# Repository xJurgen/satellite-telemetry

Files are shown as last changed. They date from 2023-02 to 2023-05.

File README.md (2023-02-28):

# satellite-telemetry

This is a college project with an objective to create a CubeSat-like device from scratch.

The code is intended for a Blackpill (STM32F411CE) board and its functionality provides an access to the satellite sensors.
In the final design the Blackpill is connected to an RPi Zero W (V1.1) via USART1 and responds on the RPi requests.

Implemented features:
	
	- Command processing
	- Communication on USART1

Work in progress:
	
	- Light and temperature sensing using ADC

Planned features:

	- Battery management (solar panels input, battery output, shut-off when critically low level of battery..)
	- Gyroscope reading (?)

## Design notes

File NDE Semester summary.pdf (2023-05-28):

Space Applications Study Course 25.4.2023

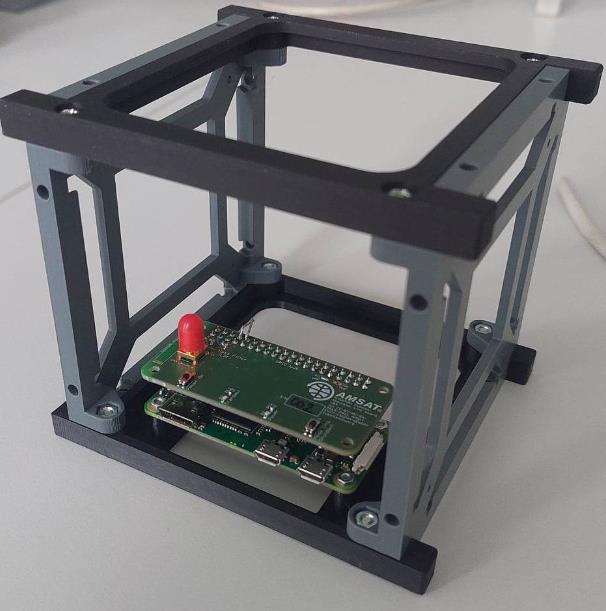
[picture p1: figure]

D. Sedláček (221347), A. Bekeč (221096), M. Borovička (208436), M. Picka (201573), M. Roman (222951), J. Veverka (205866)

### MPA-NDE Semestral Report: Development of a Power PCB Control Board for CubeSatSim Educational Platform

Project Overview

At the beginning of the semester, a series of basic tests was conducted to familiarize students with the CubeSatSim software and the Raspberry Pi Zero platform. These tests included Automated Frequency Shift Keying (AFSK) Mode Tests, Slow Scan Television (SSTV) Tests, Frequency Shift Keying (FSK), and Binary Phase Shift Keying (BPSK) FoxTelem Tests. These experiments laid the foundation for understanding the communication and telemetry protocols commonly used in nanosatellite technology.

Based on the provided platform, the class identified an opportunity to improve the CubeSatSim design by proposing a new power control board PCB. The aim was to enhance the power management capabilities of the simulated CubeSat, mainly to offer alternative options to provide power to the whole system. Throughout the remainder of the semester, the focus was centered around the design and development of this new power control board. The project was divided into several phases: initial testing, research, feasibility study, prototyping, schematic design, software development, PCB design, and fabrication & testing. By the end of the semester, the class successfully completed the design of the PCB and partially demonstrated its functionality.

Phase Zero: Initial Testing

In its initial state, the CubeSat consisted of a Raspberry pi zero and a CubeSatSim Lite board. These components were placed in the basic frame structure. As can be seen on Figure 1.

Figure 1 Initial state

The communication tests were performed first with the SDRsharp program. An RTL-SDR R860T2 USB receiver was connected to the computer, with the help of which this communication was successfully completed. Testing of sending basic telemetry data was done using the FoxTelem program. A Finally, a test of sending a picture using the MMSSTV program was also carried out. This program works in cooperation with SDRsharp, with which it was connected using a virtual audio cable and decoded the image from the audio signal. All tests were successful and created a basis for further improvement possibilities

Phase One: Research

As CubeSats are very small, as they aim to be very cost-effective, one of the key challenges in their design is ensuring reliable and efficient ways to generate power and coming up with methods for power management.

Solar Panels are the most common power source for CubeSats. There are several types of solar panels, including monocrystalline, polycrystalline, and thin-film panels. Typically, CubeSats use monocrystalline (often multi-junction) layers as they offer the highest efficiency. An exemplary structure is a triple-junction GaAs cell. These solar cells are lightweight, have a high power-to-weight ratio, and can provide power for the duration of the CubeSat mission. Depending on the CubeSat's power requirements, solar panels can be mounted on one or more sides of the satellite or even be deployable to maximize energy generation.

Radioisotope Thermoelectric Generators (RTGs) are an alternative power source for CubeSats, particularly for deep-space missions due to a low-starlight environment. They generate electricity by converting the heat released from the natural decay of radioisotopes, such as plutonium-238. Power is converted via thermocouples. Although RTGs offer a long-lasting and stable power source, their use in CubeSats is limited due to their high cost, regulatory restrictions, and potential safety concerns.

Other emerging energy harvesting methods involve energy harvesting from alternative sources. They aim to capture and convert ambient energy from the satellite's environment into usable electrical power. Potential energy harvesting sources for CubeSats include vibrational energy from the satellite's deployment mechanism or other onboard systems, thermal gradients from satellite components, and even electromagnetic energy from radiofrequency signals. While energy harvesting technologies are still in the early stages of development, they hold promise for supplementing traditional power sources and increasing CubeSat mission lifetimes.

Batteries serve as energy storage devices for CubeSats, ensuring that power is available during periods of eclipse or when solar energy generation is insufficient. Commonly used batteries for CubeSats include lithium-ion (Li-ion), lithium-polymer (LiPo), and lithium iron phosphate (LiFePO4) batteries. These battery types offer a high energy density, long cycle life, and a relatively stable voltage output.

Phase Two: Feasibility Study

Solar energy is an abundant and renewable resource, making it an ideal power source for CubeSats. As while they operate in Low Earth Orbit (LEO), they are exposed to sunlight for a significant portion of their orbital period, which can be efficiently converted into electrical energy, providing a continuous supply of power to the satellite. Triple-junction GaAs cells have a well-established track record in space applications, as they offer excellent power-to-weight ratios. However, considering the educational nature and budget constraints of the project, triple-junction cells can be beneficially replaced with their low-cost, less-efficient alternatives.

Batteries serve as an essential complement to solar panels, providing energy storage capabilities that ensure power is available during periods when solar energy generation is insufficient or completely absent. This energy storage solution ensures the continuous operation of the CubeSat's systems and instruments, allowing the system to operate without interruption.

Solar panels and batteries are relatively simple for integration, making them suitable for our educational test platform, where ease of use and accessibility are important factors. Students can focus on learning the principles of power management and satellite design without being overly precautious due to risks associated with such expensive components.

Phase Three: Prototyping

The main body of the prototyping work consisted of verifying the feasibility of the planned circuits, as well as the verification of proper internal and external communication of the satellite.

The first phase of prototyping included the creation of several simple battery management circuits:

- Case 1: 2 AA Batteries without a DC-DC converter
- Case 2: 3 AA Batteries without a DC-DC converter
- Case 3: 2 AA Batteries with a DC-DC converter
- Case 4: 3 AA Batteries with a DC-DC converter

During this phase it was shown that the satellite raspberry pi zero module cannot be powered purely from battery power, as it causes charging and discharging of the raspberry capacitors, causing looping restarts. Therefore, a DC-DC converter was used to convert from the typical 2.7 V for 2xAA and 4.1V for 3xAA to a stable source of 5V.

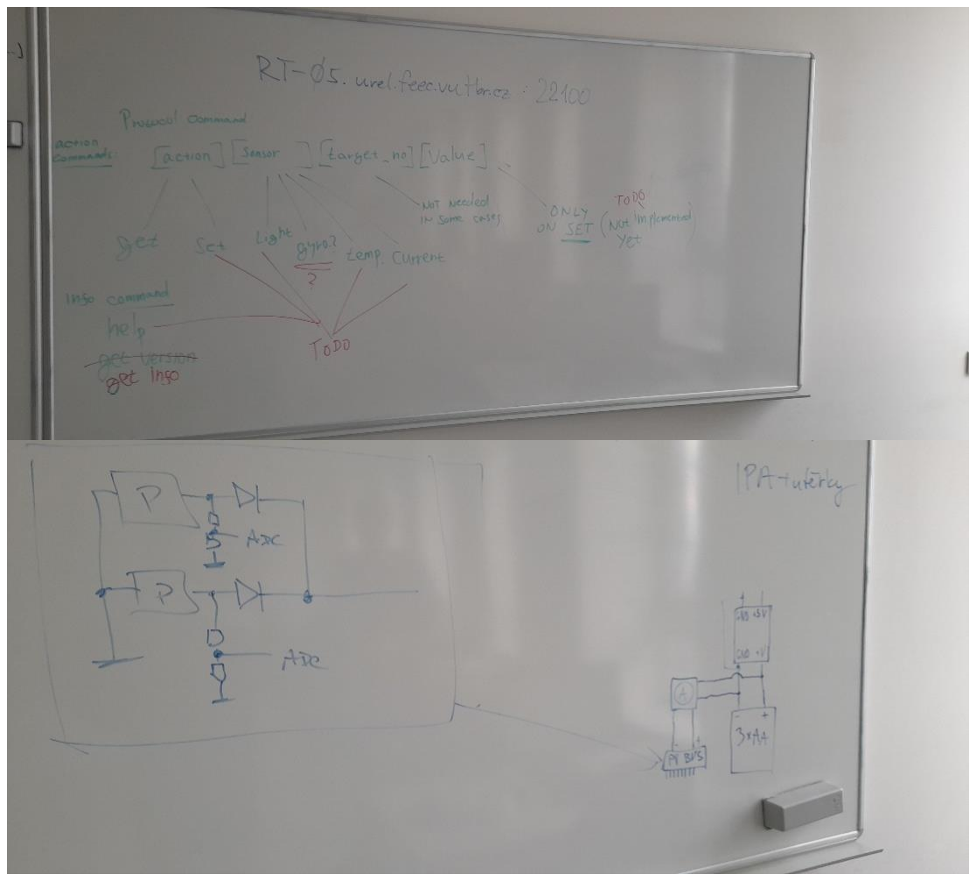
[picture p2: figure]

It should be noted that during the creation of this circuit a new safety requirement was created, since the DC-DC circuit immediately gets destroyed if the input voltage is higher than the set output voltage. Therefore, all further testing requires that the conversion rate is known and within the requirement.

Once the basic circuit had been created, the solar cells were prepared for use and the battery management system had been extended.

- Case 5: 2 AA Batteries with a DC-DC converter Solar Panel circuit (normal diodes)
- Case 6: 2 AA Batteries with a DC-DC converter Solar Panel circuit (schottky diodes)
- Case 7: 2 AA Batteries without a DC-DC converter Solar Panel circuit (schottky diodes)

The solar panel circuit consisted of the following components:

- 4x Solar Panels 90x60mm
- 4x Diodes for circuit protection (normal, later schottky)
- On/off switch for controlling current flow from PV circuit to battery circuit

The final form which was successfully tested and verfied was Case 6, which was also used in the integrated BMS/PSU circuit.

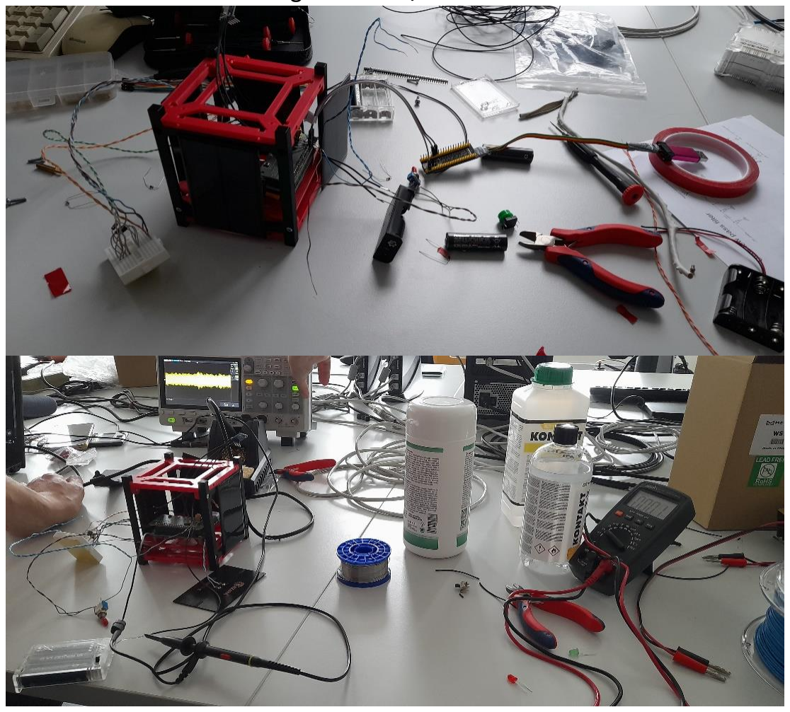
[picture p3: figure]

During the prototyping phase of the circuit, the following outputs were gathered:

- The batteries are insufficient to power the raspberry pi by themselves
- If the voltage of the batteries falls below 2.4V the system experiences brownout
- The maximum power output of the solar paneling of the satellite is in units of mA, possibly showing insufficient power generation.
- Schottky diodes slightly increase the power output of the PV panels.

The third phase of the prototyping work consisted of ensuring communication occurred between the PSU blackpill module and the main raspberry pi module.

In the initial phases of prototyping, UART protocol was chosen instead of i2c for several reasons, including it being considered more stable for spacecraft, however the main reason being the number of channels available if the blackpill module had been chosen.

There were two parts of this effort, the first part consisted of the circuit team creating a communication protocol that would be transmitted to the raspberry pi. The second part consisted of the prototyping team modifying the raspberry pi code to accept and correctly interpret the received data.

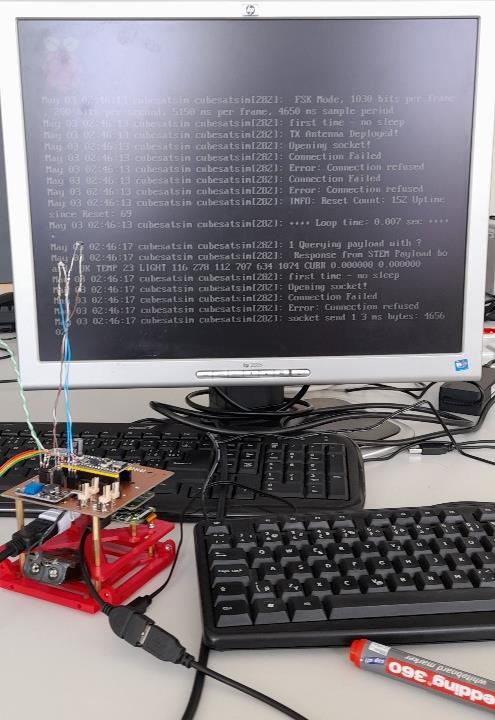
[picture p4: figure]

After several attempts a connection had successfully been made and the correct telemetry data has been confirmed to have arrived at the testing ground station. This phase took the most amount of time as several issues had arisen:

- The UART protocol had to precisely replicate the behavior of the expected STEM payload.
- Blackpill resets have shown to be transmitting garbage data to the raspberry.
- Raspberry seems to partially block RX/TX communication in certain cases, such as unexpected characters at the ttyAMA0 terminal.
- The parts of the code containing the communication with the STEM payload had to be found and reverse engineered.

The communication protocol had been determined to work as follows:

1. CubeSatSim sends out aarestart signal to the payload (a single ‘R’) to tty/AMA0 at 115200 bauds
2. Payload restarts (dummy restart) and responds ‘OK’
3. If successful, CubeSatSim will periodically (approx. Every 5s) send out a query (‘?’) signal to the payload
4. Payload responds with ‘OK TEMP <Val1> LIGHT <Val1> <Val2> <Val3> <Val4> <Val5> <Val6> CURR <Val1> <Val2>’
5. CubeSatSim processes the data according to csv files in spacecraft/FoxTelem<version> folders, and transmits them
6. FoxTelem on the ground station receives this data

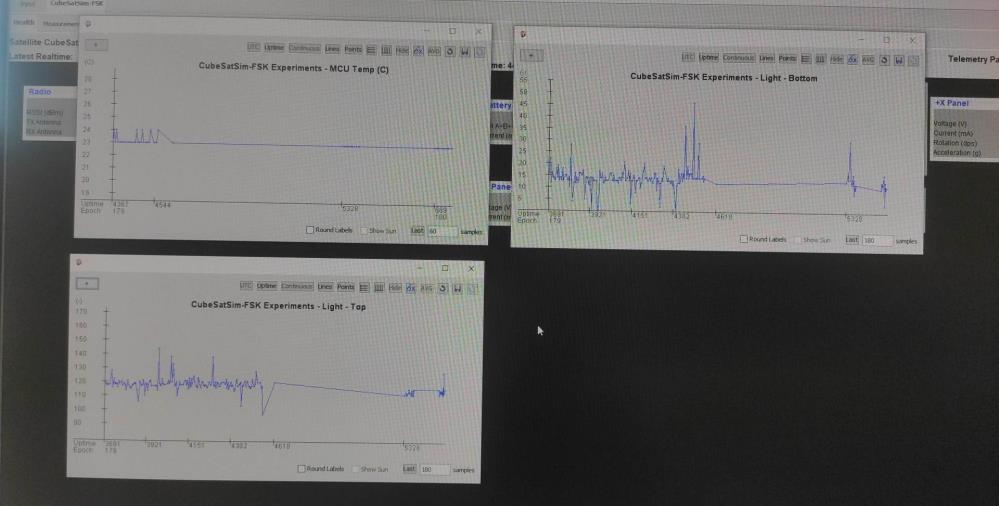
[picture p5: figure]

Successful light sensor reading during constant cubesat rotation:

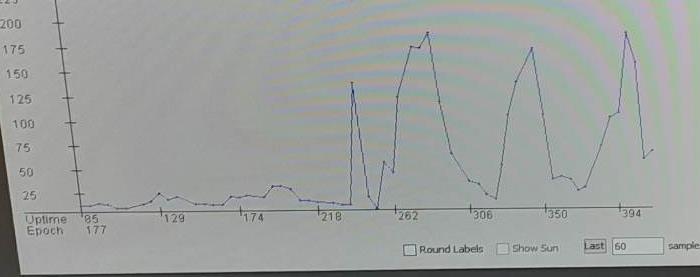
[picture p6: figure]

Phase Four: Schematic Design

In this phase, the integration of solar panels and batteries to power the Raspberry Pi Zero was laid out. The schematic design provides a foundation for understanding the connections and components involved in creating a base energy source for the Raspberry Pi. The design aims to provide the test platform with power generation and power storage while maintaining simplicity and cost-effectiveness. The final schematic is displayed in Figure 1.

Schottky diodes act as blocking diodes, preventing the reverse flow of current from the controller or other parts of the circuit back to the solar panels. This ensures that the energy stored in the batteries isn't drained back into the solar panels. Additionally, these diodes have a relatively low forward voltage drop (typically 0.2-0.5V), which minimizes power loss across the diode when conducting current. This is beneficial for the CubeSat, as power efficiency is crucial due to the limited energy available from the solar panels.

A polyfuse is included in series with the battery to provide protection against overcurrent and short-circuit events. It is a crucial safety component that can help prevent damage to the battery and other electronic components in the circuit. When the current in the circuit exceeds a predefined threshold, the polyfuse's resistance increases rapidly, effectively limiting the current flow.

A DC-DC converter MT6308 is used in the circuit for the purpose of regulating and converting the voltage level. The microcontroller requires a different voltage level than that provided by the solar panels and the battery. The converter steps up the input voltage to 5V to match the required voltage level for the microcontroller.

A P-MOS Transistor allows controlled power delivery to the Raspberry Pi Zero. By controlling the gate of the PMOS transistor, the other MCU can enable or disable power to the Raspberry Pi Zero based on specific conditions or requirements.

The MCU can monitor the current and voltage levels in the system and disable the PMOS transistor if an overcurrent or overvoltage condition is detected.

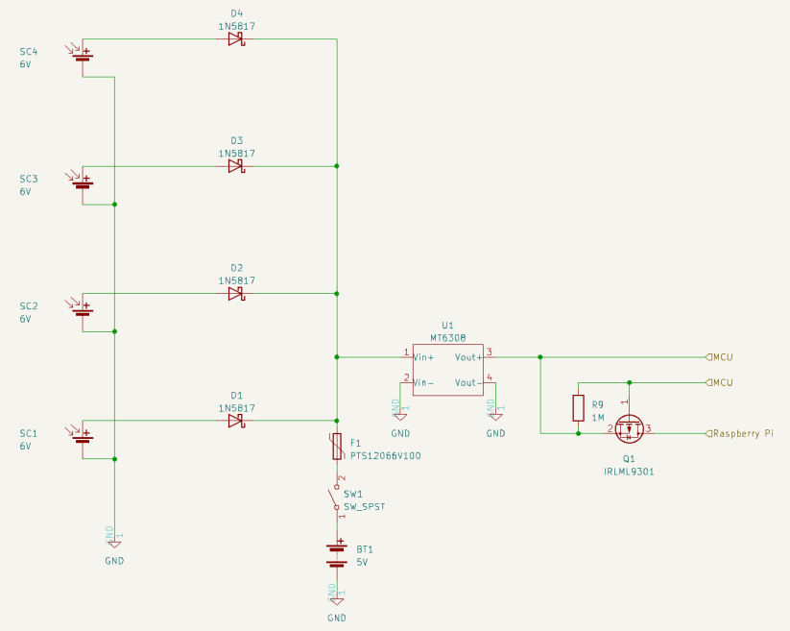
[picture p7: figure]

Figure 2. - Schematic design of the power feed.

Phase Five: Software Development

Based on the prototype and the project requirements we designed a code. The code is written in LibOpenCM3, which is a library focused on development of Cortex-M3 architecture devices. The code consists of main part which handles the communication. Based on received data the code executes one of following operations:

- ‘R’: Device responds with ‘OK’ and then dummy resets itself
- ‘?’: Device returns a string containing telemetrics
- ‘help’ + enter: Debug command - device returns a list of manual commands (every of the command needs to be sent manually by enter)

The code is designed in a way that ‘R’ and ‘?’ request has the most priority and is handled by IRQ. Every other command is also handled by IRQ but is not executed until enabled (debug commands are commented by default) and the character for ‘enter’ appears.

The code is designed around IRQ, which handles most of the program's workflow. Other necessary things like peripheral setup are done usually only once.

Phase Six: PCB Design

Same as the code – based on the prototype and the project requirements, we designed and created a printed circuit board. The design itself was divided into 2 parts – circuit design and PCB design in which the circuit board was divided between the BMS (battery management system) and the peripherals connection design. The most visible part of the PCB is the hole placed between the MCU and RPi connector. This hole is designed to let the antenna through.

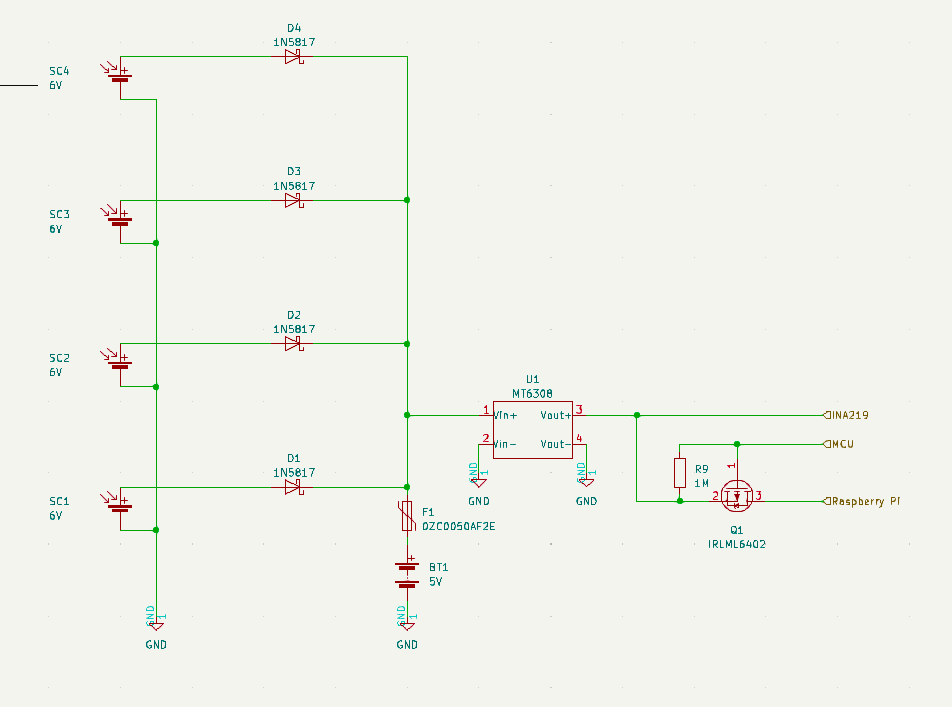
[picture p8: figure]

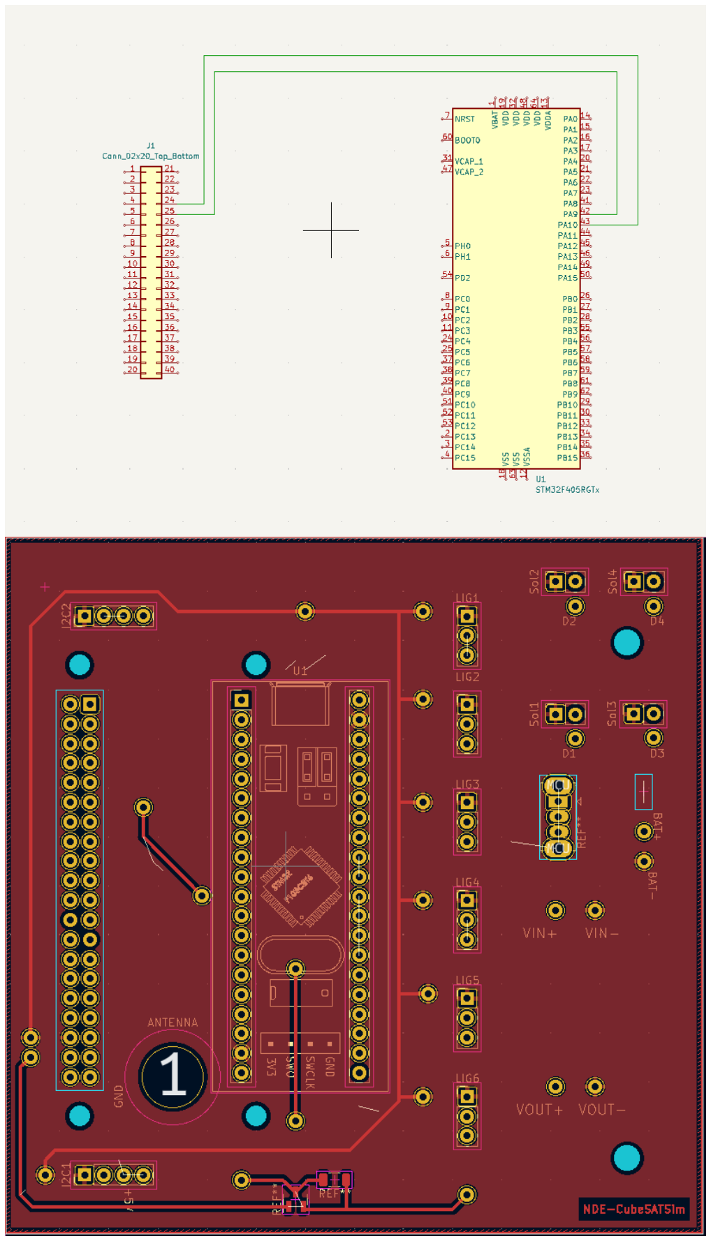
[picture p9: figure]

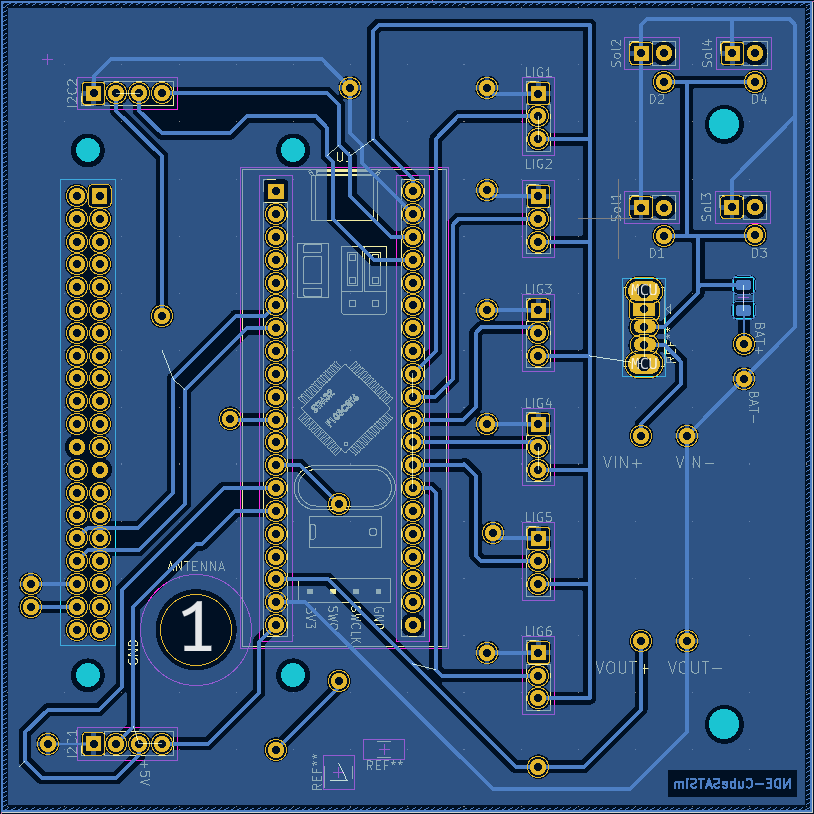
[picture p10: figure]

Phase Seven: Fabrication & Testing

During the testing phase we encountered multiple problems.
We successfully managed to fix everything and got the system running.

List of encountered problems:

- PCB Design:
- Wrongly designed connectors for solar panels – resolved by soldering the connector onto the diode and piece of wire.
- Connector for RPi header designed for wrong side – fixed by wires bridging the gap on one side to another.
- MOSFET orientation design was not according to the datasheet – fixed by rotating the MOSFET.
- Power system problems – Fixed by soldering a parallel capacitor to the powerline and removing the fuse, resulting in stable power supply.

- Redesign of RPi header placement needed – to enable easy access to HDMI and microUSB ports.
- SW + FW:
- Communications problem (stopped responding after a while) – resolved by implementing priority line in ISR.
- Communications problem (payload content incomplete) - resolved by increasing the size of the buffer containing the message.
- Communications problem (echo) - resolved by disabling the TX response.
- Communications problem (waiting for ‘enter’) - On commands ‘R’ and ‘?’ the MCU was waiting for the ‘enter’ character. Since these commands are sent by computer automatically and don’t wait for confirmation, the problem was resolved by handling in poll or in ISR.
- RPi problem (wrong payload name) - renamed.
- RPI problem (service fails to start) - resolved by reinstalling the CubeSatSim files.
- RPi declining communication from MCU – resolved by changing the batteries.
- RPi displaying (almost) static data – caused by buffer overflow which happened because of too frequent data sending from the MCU. Resolved by slowing the data flow.

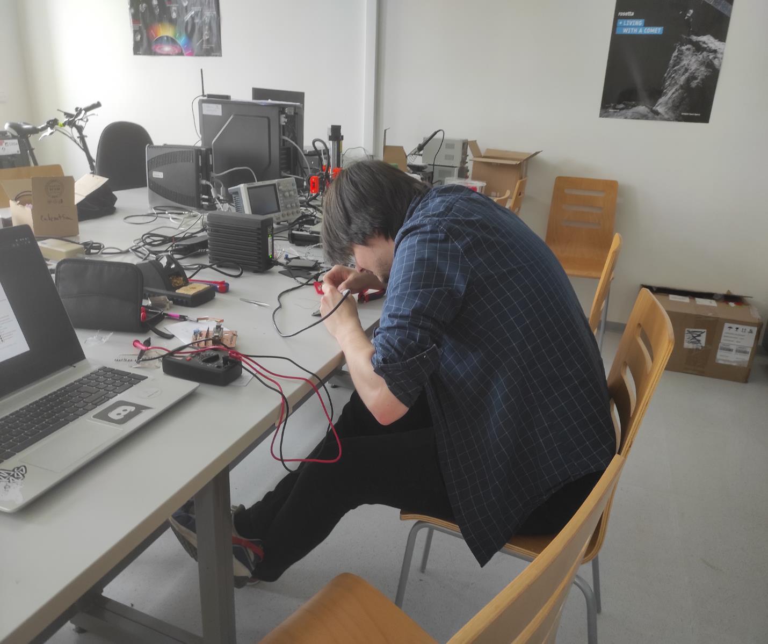
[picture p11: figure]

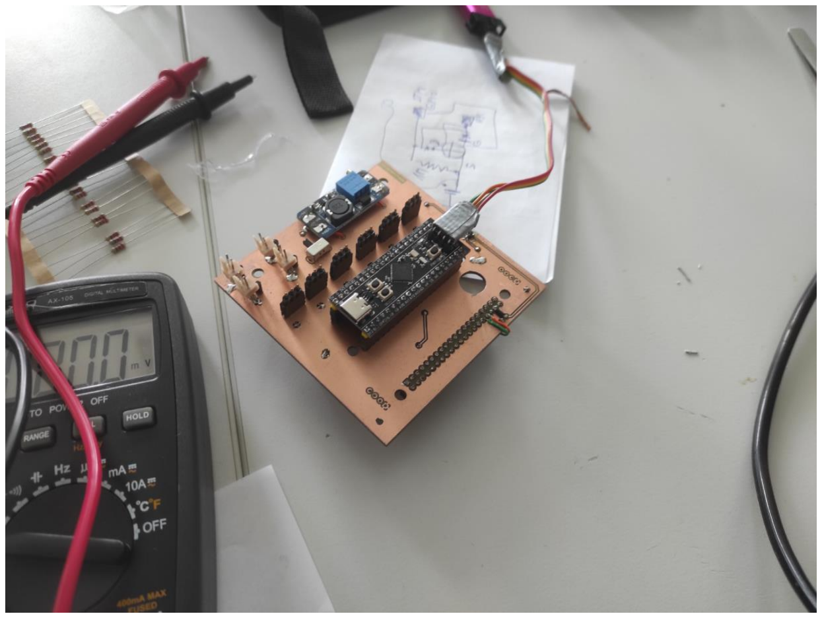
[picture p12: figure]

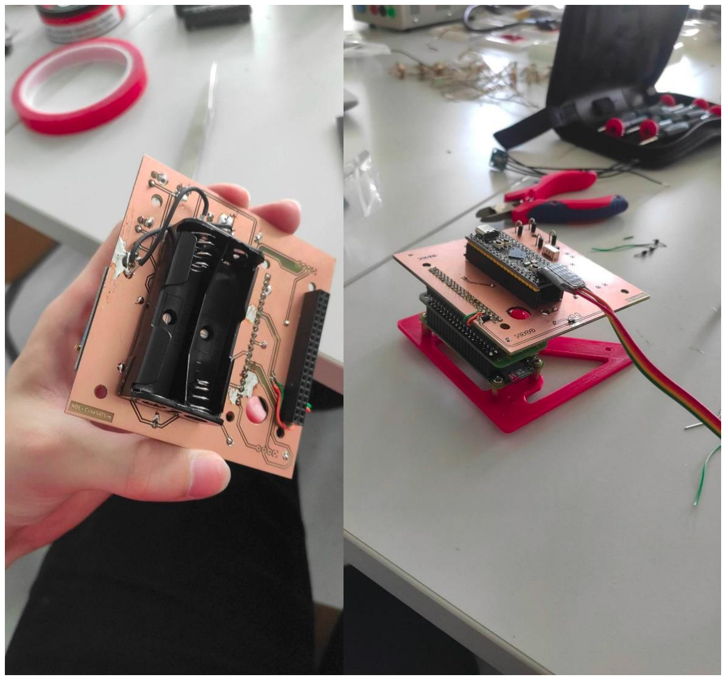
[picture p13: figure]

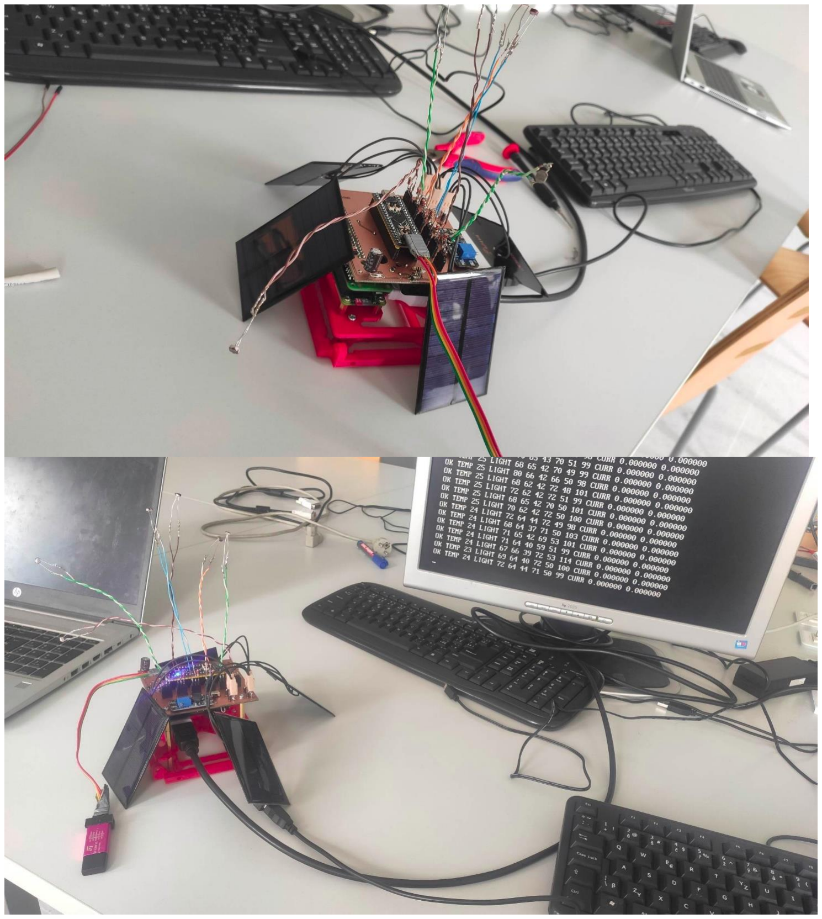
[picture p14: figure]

### Structure and design

CubeSat structure was designed from 3d printed parts with modularity in mind. Inside CubeSat houses modular and height adjusted platforms for attachment of components. Outside of the CubeSat has 4 modular solar panels and resistor holders, allowing quick and easy disassembly.

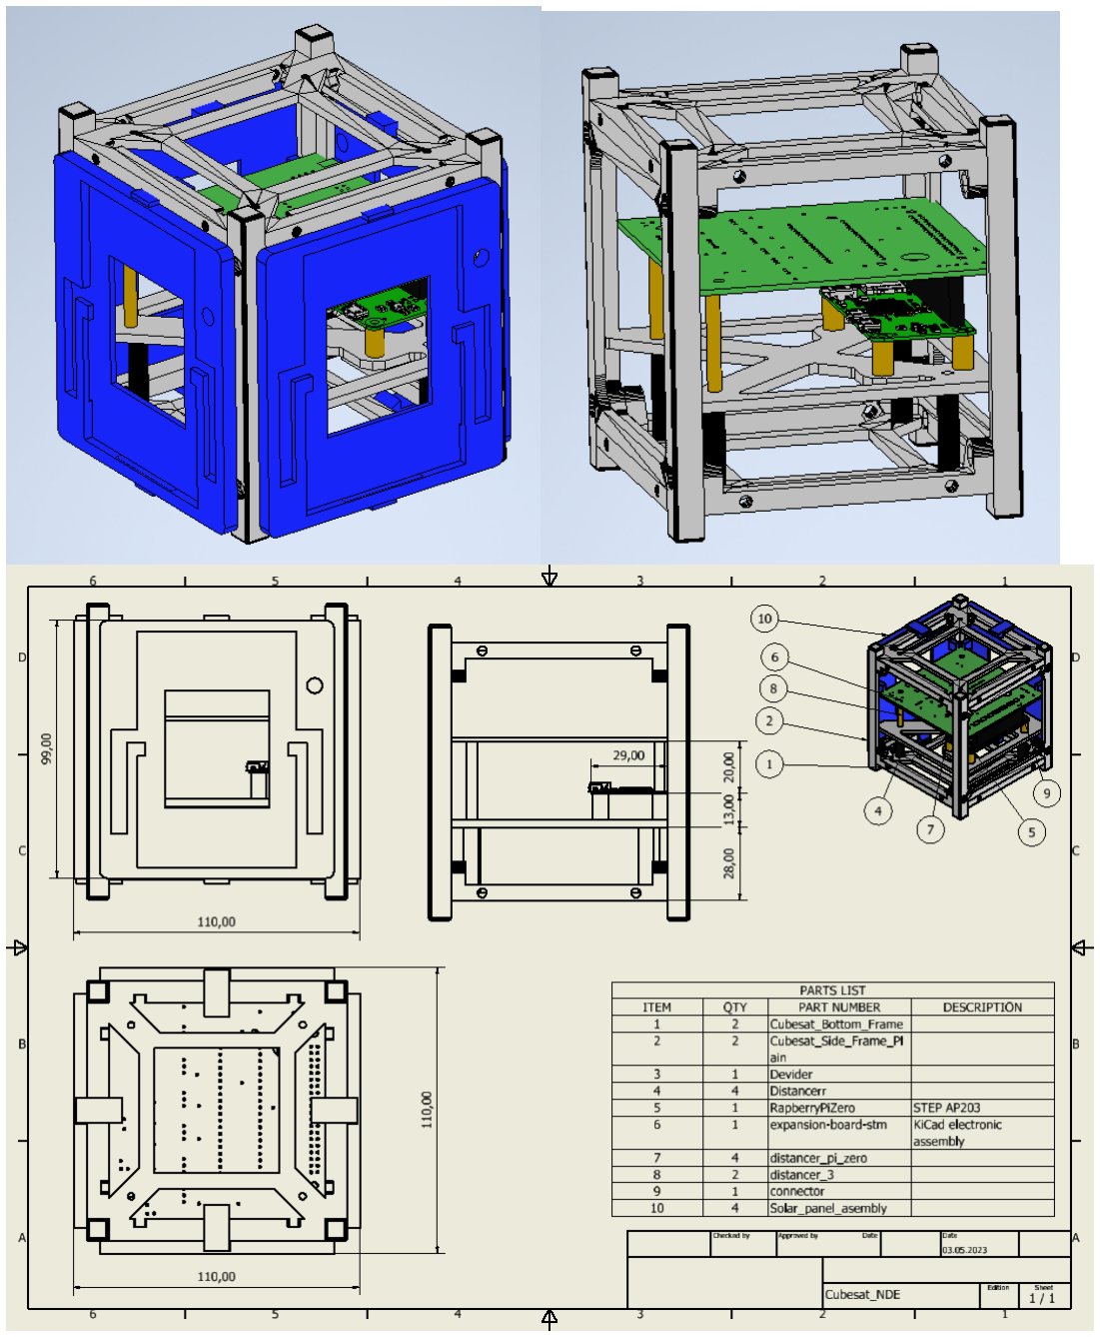
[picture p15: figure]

Side-solar panels housing:

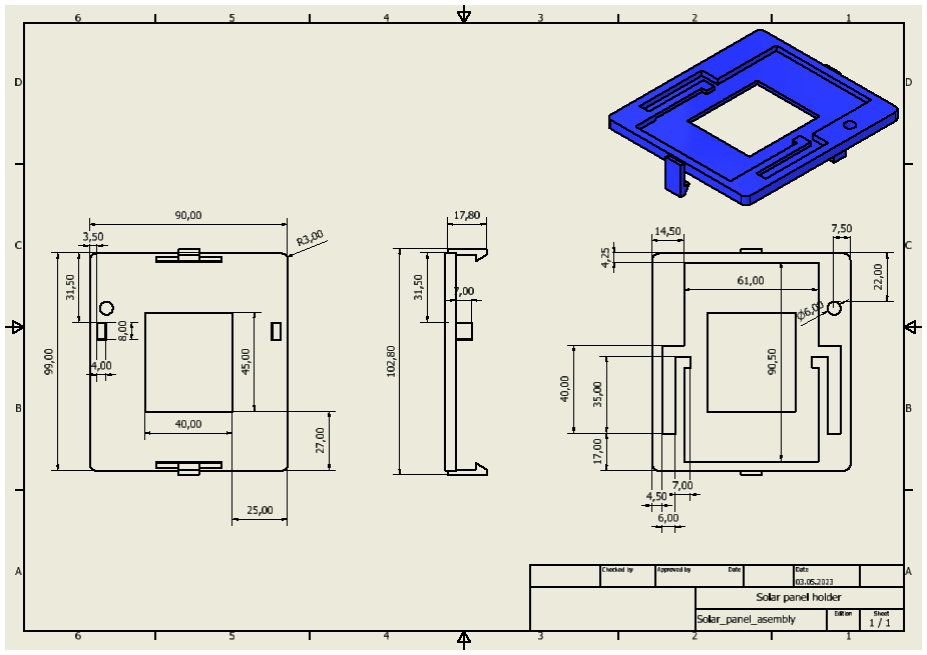
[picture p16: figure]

Final assembly of CubeSat demonstrator

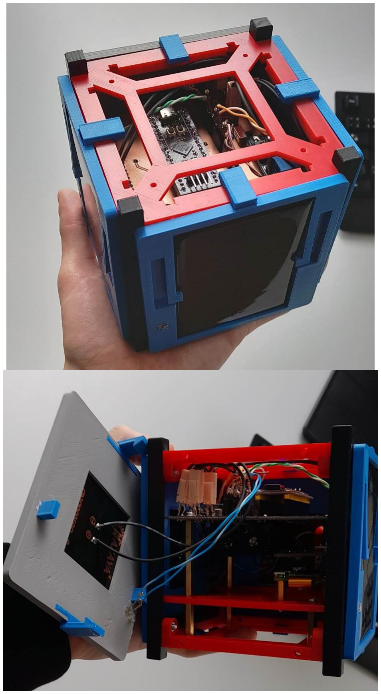
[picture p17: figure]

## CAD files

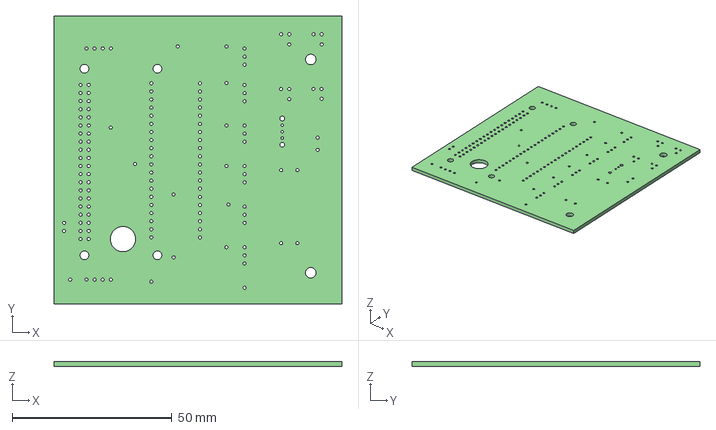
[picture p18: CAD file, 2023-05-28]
expansion-board-stm/NDE-PCB.step
90.2 x 90.2 x 1.60 mm

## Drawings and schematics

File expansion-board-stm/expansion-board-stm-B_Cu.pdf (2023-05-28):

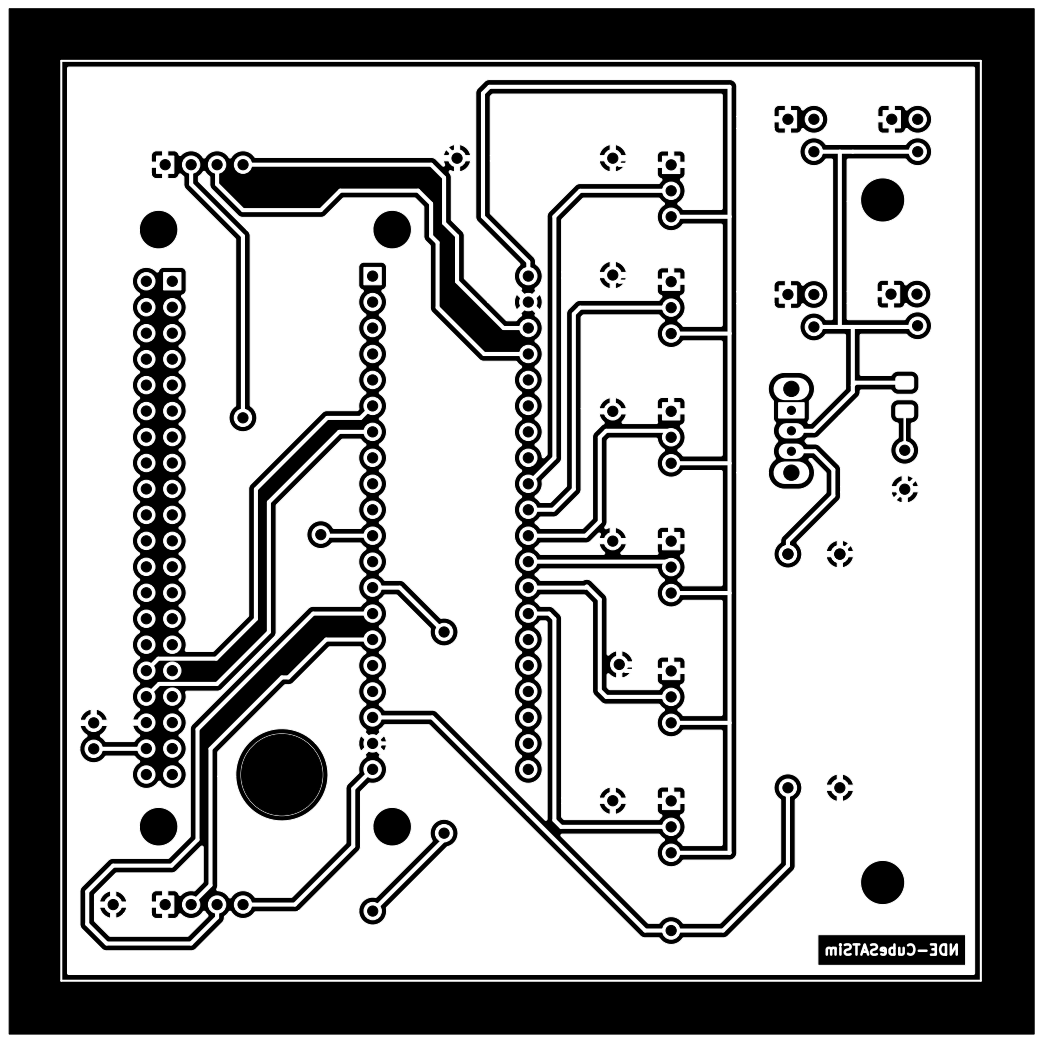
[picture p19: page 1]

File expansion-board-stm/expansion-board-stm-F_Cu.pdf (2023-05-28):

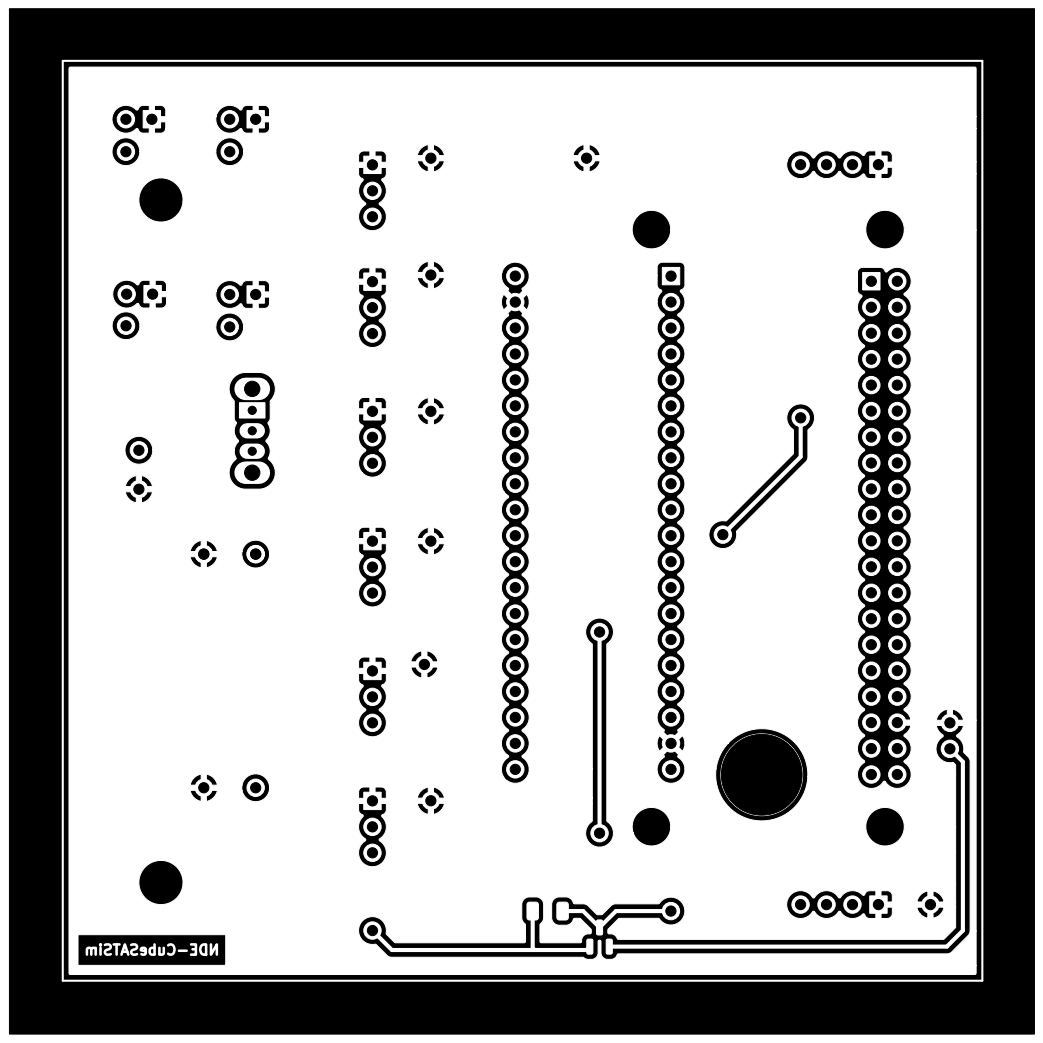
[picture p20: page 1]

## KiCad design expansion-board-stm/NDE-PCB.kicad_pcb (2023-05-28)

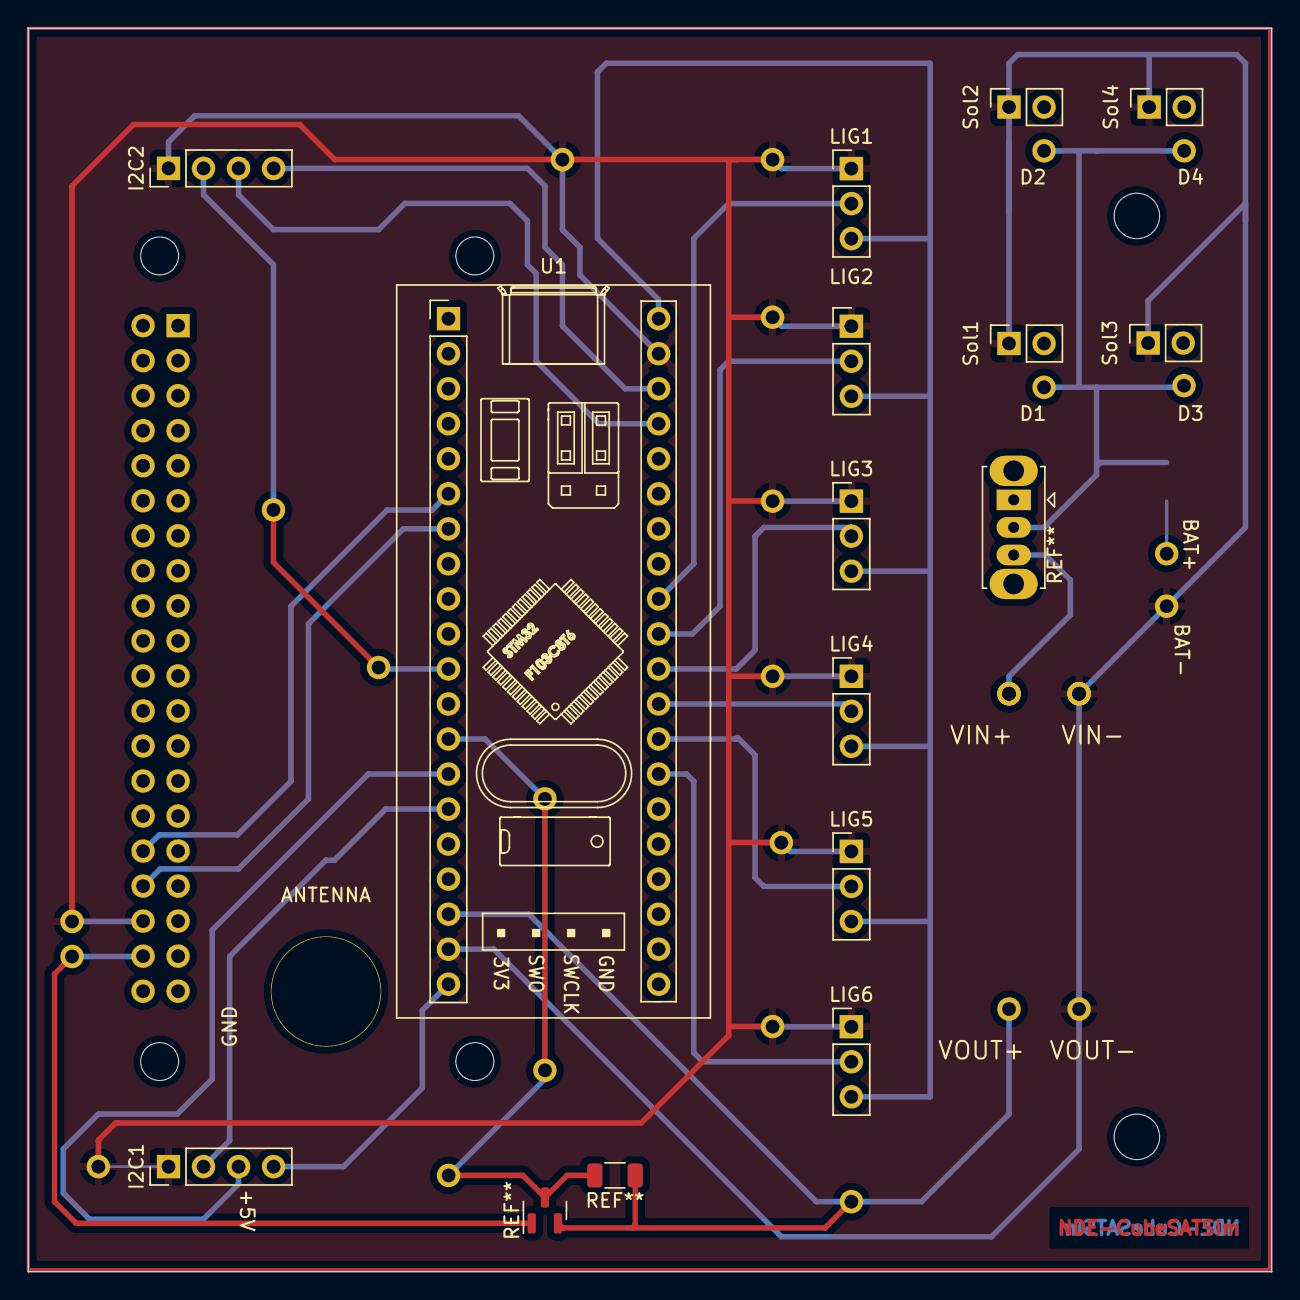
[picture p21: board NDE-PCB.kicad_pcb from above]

Board: 2 copper layers, 90.2 x 90.2 mm, 15 parts (1 on the bottom side), 2 nets.

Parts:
ANTENNA: MountingHole_6mm_Pad_TopOnly
I2C1, I2C2: PinHeader_1x04_P2.54mm_Vertical
J1: Conn_02x20_Top_Bottom; PinHeader_2x20_P2.54mm_Vertical
LIG1, LIG2, LIG3, LIG4, LIG5, LIG6: PinHeader_1x03_P2.54mm_Vertical
Sol1, Sol2, Sol3, Sol4: PinSocket_1x02_P2.54mm_Vertical
U1: STM32F405RGTx; YAAJ_BluePill_1

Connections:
GND: I2C1.1, I2C2.1, J1.36, LIG1.1, LIG2.1, LIG3.1, LIG4.1, LIG5.1, LIG6.1, Sol1.1, Sol2.1, Sol3.1, Sol4.1, U1.gnd (PC8)
MCU: I2C1.2, I2C1.3, I2C1.4, I2C2.2, I2C2.3, I2C2.4, J1.32, J1.34, J1.38, LIG1.3, LIG1.adc6, LIG2.3, LIG2.adc5, LIG3.3, LIG3.adc4, LIG4.3, LIG4.adc3, LIG5.3, LIG5.adc2, LIG6.3, LIG6.adc1, U1.6 (PH1), U1.7 (NRST), U1.13 (VDDA), U1.18 (VSS), U1.20 (PA4), U1.27 (PB1), U1.28 (PB2), U1.29 (PB10), U1.30 (PB11), U1.31 (VCAP_1), U1.32 (VDD), U1.38 (PC7), U1.40 (PC9), U1.scl1 (PA0), U1.scl2 (PC6), U1.sda1 (PA1), U1.sda2 (PC3)

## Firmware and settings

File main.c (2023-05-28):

/* This project is based on libopencm3 STM32F4 usart_irq example */
/* Modified by: Jiří Veverka (xvever12@vutbr.cz) */
#include "libs.h"
#include "version.h"

#include <libopencm3/stm32/rcc.h>
#include <libopencm3/cm3/systick.h>
#include <libopencm3/cm3/scs.h>
#include <libopencm3/cm3/scb.h>
#include <libopencm3/stm32/gpio.h>
#include <libopencm3/stm32/usart.h>
#include <libopencm3/cm3/nvic.h>

#include "adc_control.h"

#define IRQ_PRI_USBUSART        (1 << 4)

void get_all_values();

static void clock_setup(void)
{
	// Enable GPIOC clock for LED & USARTs.
	rcc_periph_clock_enable(RCC_GPIOC);
	rcc_periph_clock_enable(RCC_GPIOB);
	rcc_periph_clock_enable(RCC_GPIOA);

	// Enable clocks for USART1.
	rcc_periph_clock_enable(RCC_USART1);

	// Enable clocks for ADC
	rcc_periph_clock_enable(RCC_ADC1);
}

static void usart_setup(void)
{
	// Setup GPIO pins for USART1 transmit.
	gpio_mode_setup(GPIOA, GPIO_MODE_AF, GPIO_PUPD_NONE, GPIO9);

	// Setup GPIO pins for USART1 receive.
	gpio_mode_setup(GPIOA, GPIO_MODE_AF, GPIO_PUPD_NONE, GPIO10);
	gpio_set_output_options(GPIOA, GPIO_OTYPE_OD, GPIO_OSPEED_25MHZ, GPIO10);

	// Setup USART1 TX and RX pin as alternate function.
	gpio_set_af(GPIOA, GPIO_AF7, GPIO9);
	gpio_set_af(GPIOA, GPIO_AF7, GPIO10);

	// Setup USART1 parameters.
	usart_set_baudrate(USART1, 115200);
	usart_set_databits(USART1, 8);
	usart_set_stopbits(USART1, USART_STOPBITS_1);
	usart_set_mode(USART1, USART_MODE_TX_RX);
	usart_set_parity(USART1, USART_PARITY_NONE);
	usart_set_flow_control(USART1, USART_FLOWCONTROL_NONE);

	// Enable USART1 Receive interrupt.
	usart_enable_rx_interrupt(USART1);

	// Enable the USART.
	usart_enable(USART1);

    // Enable interrupt
    //USART1_CR1 |= USART_CR1_RXNEIE;
    //nvic_set_priority(NVIC_USART1_IRQ, IRQ_PRI_USBUSART);
    nvic_enable_irq(NVIC_USART1_IRQ);
}

static void gpio_setup(void)
{
	// Setup GPIO pin GPIO13 on GPIO port C for LED.
	gpio_mode_setup(GPIOC, GPIO_MODE_OUTPUT, GPIO_PUPD_NONE, GPIO13);
}


//DEBUG PURPOSES ONLY
/*void clear_buffer();
void parse_command();
static uint8_t command = false;
static uint8_t delete = false;
static uint8_t idx = 0;*/

int main(void)
{
	clock_setup();
	rcc_clock_setup_pll(&rcc_hse_25mhz_3v3[RCC_CLOCK_3V3_96MHZ]); //Internal clock

	gpio_mode_setup(GPIOB, GPIO_MODE_OUTPUT, GPIO_PUPD_PULLDOWN, GPIO5);

	gpio_setup();
	init_adc();
	usart_setup();

	//uint16_t data = '0';
	while (1) {
		for (int i = 0; i < 800000; i++) {   /* Wait a bit. */
			__asm__("nop");
		}

		//Tests polling the '?'
		/*
		uint16_t data = usart_recv(USART1);
		if(data == '?') {
			get_all_values();
			clear_buffer();
			data = 0;
		}*/

		//DEBUG PURPOSES ONLY
		//If we receive something else than '?' and 'R', process it in polling
		/*if (command) {
			idx = 0;
			command = false;
			parse_command();
		}*/
	}

    //Should not ever get there...
	return 0;
}


//DEBUG PURPOSES ONLY
/*#define MAX_BUFFER_SIZE		25
static uint8_t recv_buffer[MAX_BUFFER_SIZE];
static char token_buffer[MAX_BUFFER_SIZE];

static char *version = FIRMWARE_VERSION;
static char *build_time = BUILD_TIME;

void clear_buffer() {
	for (int j = 0; j < MAX_BUFFER_SIZE; j++) {
		recv_buffer[j] = 0;
		token_buffer[j] = 0;
	}
}*/

void send_message(char *message, size_t size) {
	for (size_t j = 0; j < size; j++) {
		usart_send_blocking(USART1, message[j]);
	}
	usart_send_blocking(USART1, '\r');
	usart_send_blocking(USART1, '\n');
}

void send_message_no_newline(char *message, size_t size) {
	for (size_t j = 0; j < size; j++) {
		usart_send_blocking(USART1, message[j]);
	}
}

//DEBUG PURPOSES ONLY
/*
int tokenize() {
	const char *recv = (char *)recv_buffer;
	const char *recv_end = recv + strlen(recv) + 1;
	char buf[MAX_BUFFER_SIZE];

	int scan_len = 0;

	int num = -1;

	for (; recv < recv_end && sscanf(recv, "%[^ ]%n", buf, &scan_len); recv += scan_len+1) {
		//In this version we save only the last number scanned, other are discarded. Non-numerical values are saved into separate buffer.
		//If needed, will be changed according to the to-be defined protocol in the future
		if (!sscanf(recv, "%d", &num)) {
			strcat(token_buffer, strcat(buf, " "));
		}
	}

	size_t space_pos = strlen(token_buffer);
	token_buffer[space_pos-1] = 0;

	//send_message(token_buffer, strlen(token_buffer)); //Uncomment for debug purposes

	return num;
}
*/

char message_buffer[60];
int vals[10];

void get_all_values() {

	get_temp(); // We need to initialize the internal temp. sensor before we read thus calling it once more
	vals[0] = get_temp();

	for (int i = 0; i < 800000; i++)    /* Wait a bit. */
       	__asm__("nop");


	for (int j = 1; j <= 6; j++) {

		vals[j] = get_light_val(j);

		for (int i = 0; i < 800000; i++)    // Wait a bit. -- DELETE IF TOO SLOW
     	   __asm__("nop");
	}

	float curr_volt[2] = {0.0, 0.0}; //TODO IMPLEMENT CURRENT SENSOR - Values will be of integer type and red through ADC channel

	sprintf(message_buffer, "OK TEMP %d LIGHT %d %d %d %d %d %d CURR %f %f", \
							vals[0], vals[1], vals[2], vals[3], vals[4], vals[5], vals[6], curr_volt[0], curr_volt[1]);

	send_message_no_newline(message_buffer, strlen(message_buffer));

	usart_send_blocking(USART1, '\n');
}


//This function is commented out because of backward-compatibility reasons (to keep a track of changes)
/*
void get_all_values() {
	//char num[MAX_BUFFER_SIZE] = "0";

	//send_message_no_newline("OK TEMP ", sizeof("OK TEMP "));
	get_temp();
	vals[0] = get_temp();
	//sprintf(num, "%d ", get_temp());
	//send_message_no_newline(num, sizeof(num));

	for (int i = 0; i < 800000; i++)    // Wait a bit. -- DELETE IF TOO SLOW
       	__asm__("nop");

	//send_message_no_newline("LIGHT ", sizeof("LIGHT "));
	for (int j = 1; j <= 6; j++) {
		//sprintf(num, "%d ", get_light_val(j));
		//send_message_no_newline(num, sizeof(num));
		vals[j] = get_light_val(j);

		for (int i = 0; i < 800000; i++)    // Wait a bit. -- DELETE IF TOO SLOW
     	   __asm__("nop");
	}

	//send_message_no_newline("CURR ", sizeof("CURR "));
	float curr_volt[2] = {0.0, 0.0}; //TODO IMPLEMENT CURRENT SENSOR
	//for (int j = 0; j <= 1; j++) {
	//	sprintf(num, "%lf ", curr_volt[j]);
	//	send_message_no_newline(num, sizeof(num));
	//}

	sprintf(message_buffer, "OK TEMP %d LIGHT %d %d %d %d %d %d CURR %f %f", vals[0], vals[1], vals[2], vals[3], vals[4], vals[5], vals[6], curr_volt[0], curr_volt[1]);
	send_message_no_newline(message_buffer, strlen(message_buffer));

	//usart_send_blocking(USART1, '\r');
	usart_send_blocking(USART1, '\n');
}
*/

//DEBUG PURPOSES ONLY
/*
void parse_command() {
	static char *message;
	char temp_message[MAX_BUFFER_SIZE]; //If we need to print some value into the buffered messages, we use this variable (quick workaround)

	//In this version of the communication protocol we consider only one number in the receiving sequence
	//thus the returning value of the tokenize() function is the only found number (if present) in the sequence.
	int sensor_num = tokenize();


	if (strcmp(token_buffer, "print buffer") == 0) { //TEST FUNCTION
		message = "RESPONSE!";

	} else if (strcmp(token_buffer, "get info") == 0) {
		message = version;
		send_message(message, strlen(message));
		message = build_time;

	}

	//THIS PART IS ALREADY HANDLED IN IRQ
	*//*else if (strcmp(token_buffer, "R") == 0) {
		//send_message("OK", strlen("OK"));
		message = "OK";
		//scb_reset_system();
		clock_setup();
		rcc_clock_setup_pll(&rcc_hse_25mhz_3v3[RCC_CLOCK_3V3_96MHZ]); //Internal clock

		gpio_setup();
		init_adc();
		usart_setup();

	} else if (strcmp(token_buffer, "?") == 0) {
		get_all_values();
		clear_buffer();
		return;

	} *//*else if (strcmp(token_buffer, "help") == 0) {
		message = "Available commands:\r\n"
					"\thelp - prints this dialogue\r\n"
					"\tget info - prints information about the device\r\n"
					"\tget light [n] - prints the digital value of a light sensor number [1-7]\r\n"
					"\tget temp - prints the internal temperature\r\n\r\n"
					"Everything else returns the prompt: \"Unknown command\"";

	} else if (strcmp(token_buffer, "get light") == 0) {
		if (sensor_num <= 0 || sensor_num >= 7) {
			message = "Enter valid sensor number!";
		} else {
			uint16_t val = get_light_val(sensor_num);
			sprintf(temp_message, "Sensor %d value: %d", sensor_num, val);
			message = temp_message;
		}

	} else if (strcmp(token_buffer, "get temp") == 0) {
		get_temp();
		uint16_t val = get_temp();
		sprintf(temp_message, "Temp %d", val);
		message = temp_message;

	} else {
		//message = "Unknown command!";
		message = "";
	}

	send_message(message, strlen(message));
	clear_buffer();
}
*/

void usart1_isr(void)
{
	static uint8_t data = 'A';

	// Check if we were called because of RXNE.
	if (((USART_CR1(USART1) & USART_CR1_RXNEIE) != 0) &&
	    ((USART_SR(USART1) & USART_SR_RXNE) != 0)) {

		// Retrieve the data from the peripheral.
		data = usart_recv(USART1);

		// Enable transmit interrupt so it sends back  and process the data.
		usart_enable_tx_interrupt(USART1);
	}

	// Check if we were called because of TXE.
	if (((USART_CR1(USART1) & USART_CR1_TXEIE) != 0) &&
	    ((USART_SR(USART1) & USART_SR_TXE) != 0)) {

		//If we receive 'R', respond with 'OK' as a "dummy" restart
		if (data == 'R') {
			usart_send_blocking(USART1, 'O');
			usart_send_blocking(USART1, 'K');
		} else if (data == '?') {
			get_all_values();
		}

		// Disable the TXE interrupt as we don't need it anymore.
		usart_disable_tx_interrupt(USART1);
	}
}


//This function is commented out because of backward-compatibility reasons (to keep a track of changes)
/*
void usart1_isr(void)
{
	static uint8_t data = 'A';

	// Check if we were called because of RXNE.
	if (((USART_CR1(USART1) & USART_CR1_RXNEIE) != 0) &&
	    ((USART_SR(USART1) & USART_SR_RXNE) != 0)) {

		// Indicate that we got data.
		//gpio_toggle(GPIOC, GPIO13);

		// Retrieve the data from the peripheral.
		data = usart_recv(USART1);

		if ((int)((char)data) == 13 || (int)((char)data) == 10) { //Enter - sets the content of the buffer to be processed
			if (strlen((char*) recv_buffer) != 0) {
				command = true;
				gpio_toggle(GPIOC, GPIO13);
			}
		} else if ((int)((char)data) == 127) { //Delete last char
			recv_buffer[idx] = 0;
			idx--;
			delete = true;
		} else if (idx < MAX_BUFFER_SIZE) { //If we don't want to execute the command or delete the entry, add the char to the buffer...
			if (data != '?') {
				recv_buffer[idx] = data;
				idx++;
			}
		}
		// Enable transmit interrupt so it sends back  and process the data.
		usart_enable_tx_interrupt(USART1);
	}

	// Check if we were called because of TXE.
	if (((USART_CR1(USART1) & USART_CR1_TXEIE) != 0) &&
	    ((USART_SR(USART1) & USART_SR_TXE) != 0)) {
		// THIS COMMENTED PART IS ALREADY HANDLED IN MAIN

		// Put data into the transmit register.
		*//*if (command) {
			//usart_send_blocking(USART1, '\r');
			//usart_send_blocking(USART1, '\n');
			i = 0;
			command = false;
			//gpio_toggle(GPIOC, GPIO13);
			parse_command();
		} else if (delete)...*/

		/*if (delete) {
			//COMMENTED BECAUSE WE NEEDED TO DISABLE ECHO

			//This part moves the pointer back 2 times and replaces the character in between to ' '
			//eg. "Hello|" and pressing delete will result in "Hell| "
			*//*usart_send_blocking(USART1, '\b');
			usart_send_blocking(USART1, ' ');
			usart_send_blocking(USART1, '\b');*/
		/*	delete = false;
		} else if (idx < MAX_BUFFER_SIZE) { //If buffer not full, do something
			if (data == 'R') {
				usart_send_blocking(USART1, 'O');
				usart_send_blocking(USART1, 'K');
				clear_buffer();
			} else if (data == '?') {
				get_all_values();
			}
			//DEBUG PURPOSES ONLY
			*//*else {
				//usart_send(USART1, data); //This part does echo
			}*/

		//DEBUG PURPOSES ONLY
		/*} else if (data == 'R') { //If we have full buffer, the only thing we accept is 'enter' or 'R'
			usart_send_blocking(USART1, 'O');
			usart_send_blocking(USART1, 'K');
			clear_buffer();
		}*/

		// Disable the TXE interrupt as we don't need it anymore.
		/*usart_disable_tx_interrupt(USART1);
	}
}
*/

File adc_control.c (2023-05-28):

#include "adc_control.h"

#include <libopencm3/stm32/gpio.h>
#include <libopencm3/stm32/adc.h>

void init_adc() {
    gpio_mode_setup(GPIOA, GPIO_MODE_ANALOG, GPIO_PUPD_NONE, GPIO1 | GPIO2 | GPIO3 | GPIO4 | GPIO5 | GPIO6);


    adc_power_off(ADC1);
    adc_disable_scan_mode(ADC1);

    adc_set_clk_prescale(ADC_CCR_ADCPRE_BY2);

    adc_set_right_aligned(ADC1);
    //adc_set_single_conversion_mode(ADC1);
    //adc_set_continuous_conversion_mode(ADC1);

    adc_enable_temperature_sensor();

    adc_set_sample_time_on_all_channels(ADC1, ADC_SMPR_SMP_3CYC);

    adc_set_multi_mode(ADC_CCR_MULTI_INDEPENDENT);

    adc_enable_scan_mode(ADC1);
    adc_power_on(ADC1); //Test if keep here or if to move to the reading part (due to the higher power consumption?)

    /* Wait for ADC starting up. */
    for (int i = 0; i < 800000; i++)    /* Wait a bit. */
        __asm__("nop");

    //adc_reset_calibration(ADC1);
    //adc_calibrate(ADC1);

}

uint16_t get_light_val(uint8_t sensor_num) {
    uint8_t channel[16];
    channel[0] = sensor_num;

    adc_set_regular_sequence(ADC1, 1, channel);

    adc_start_conversion_regular(ADC1);

    while(!adc_eoc(ADC1));
    uint16_t reg16 = adc_read_regular(ADC1);
    return reg16;
    //return reg16 / 4096 * 3.3;
}

#define V_25        0.76 //datasheet table 71
#define AVG_SLOPE   0.0025 //-||-
#define VSENSE      3.3/4096 //3.3 over 4096 samples

//Sampling time must not be lower than 10 micro seconds...

uint16_t get_temp() {
    uint8_t channel[16];
    channel[0] = ADC_CHANNEL_TEMP_F42;

    adc_set_regular_sequence(ADC1, 1, channel);

    adc_start_conversion_regular(ADC1);

    while(!adc_eoc(ADC1));
    uint16_t reg16 = adc_read_regular(ADC1);
    //return V_25 - reg16;
    uint16_t temp = ((V_25 - (reg16*VSENSE)) / AVG_SLOPE) + 25; //Datasheet formula
    return temp;
}

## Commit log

2023-02-28 Prepare testing infrastructure for adc
2023-02-28 Check if called sensor number is in range
2023-02-28 Rename adc_light to adc_control since we will use it for a temperature as well
2023-03-02 Add KiCAD files for the expansion board
    This commit doesn't contain the imported models used.
    I will add them in the future.
    [expansion-board-stm.kicad_pcb, expansion-board-stm.kicad_sch]
2023-03-20 Fix ADC reading
2023-03-20 UART: Fix communication, add new commands
    - Fix: HSE set to 96MHz to fix the UART communication
    - Addition: Parsing of the command "?" which returns all the data needed for the satellite antenna
    [main.c]
2023-03-20 BMS: Prepare the .c and .h files for future work
2023-04-03 main: add support for command "R" which resets the device
    [main.c]
2023-05-28 Update PCB layout for the satellite + PDF Documentation of the project
    Known issues: Redesign needed for wrong traces near the RPi connector
    and for the MOSFET wrong orientation.
    Also needs to rethink the powerline and change the position of the
    fuse (place it between the DC/DC converter output and the MOSFET
    instead on the DC/DC converter input).
    [NDE-PCB.kicad_pcb, NDE-PCB.kicad_sch, NDE-PCB.step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]
